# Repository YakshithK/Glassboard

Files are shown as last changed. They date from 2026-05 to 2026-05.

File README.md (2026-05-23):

# Glassboard

A transparent NFC business card that lights up when you tap your phone to it. No battery. No charging. Ever.

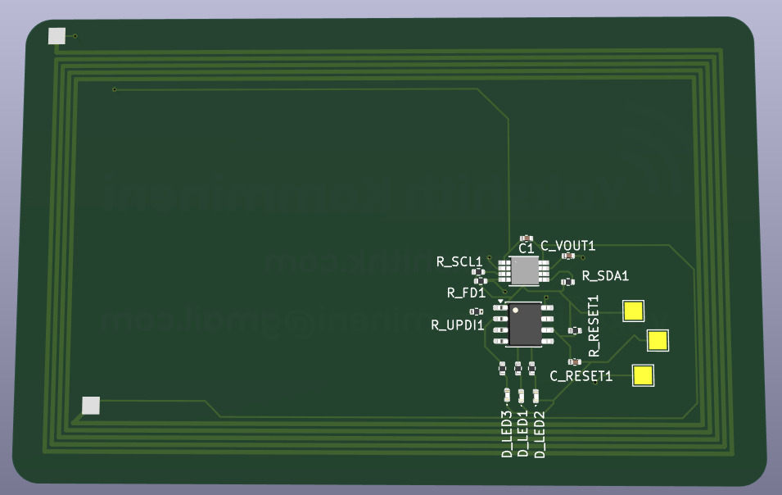
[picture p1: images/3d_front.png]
3D Front

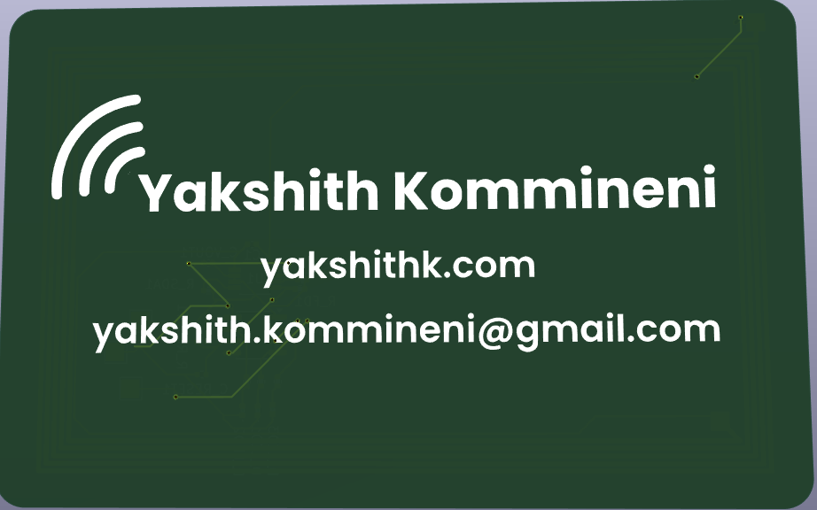
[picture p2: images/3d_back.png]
3D Back


---

## What is it

Glassboard is a credit card sized transparent circuit board. It stores my contact info and portfolio link using NFC. When someone taps their phone to it, two things happen at once: their phone opens my portfolio link, and three green LEDs on the card light up and animate.

The entire card runs off the energy from the phone's own NFC signal. There is no battery inside. Nothing to charge. The card just sits in your wallet and works whenever someone taps it.

Because it's built on a transparent substrate, you can see through the card. Every trace, every component, and the antenna spiral are all visible. It looks like a piece of glass with circuits inside.

---

## Why I made it

I kept handing people plain paper business cards at hackathons. It felt wrong. I build hardware, but the card said nothing about that.

I wanted a card that proved what I do the moment someone touched it. So I built one.

---

## How it works

The card has two chips on it.

The first is the **NT3H2111**, an NFC chip from NXP. It stores my URL in its memory and harvests power from the phone's NFC field. When a phone gets close, the chip outputs around 3V on its power pin, which powers everything else on the card.

The second is the **ATtiny202**, a tiny microcontroller. It spends almost all of its time asleep, drawing basically no power. When the NFC chip detects a phone, it sends a signal to the ATtiny, which wakes up instantly, runs the LED animation for about 2 seconds, then goes back to sleep.

The antenna is a copper spiral coil built directly into the circuit board. It has 5 turns and is tuned to 13.56 MHz, which is the frequency all NFC phones use.

The three LEDs are green because green LEDs turn on at a lower voltage than blue or white ones, which matters a lot when you're running off harvested power.

---

## How to use it

**Tapping it:**
Hold the card against the back of any NFC enabled phone (most smartphones made after 2015 have NFC). The phone will show a notification to open a link. Tap it. The LEDs on the card will also light up at the same time.

If nothing happens, try moving the card around slowly. The NFC antenna in phones is usually near the top or center of the back.

**Changing the URL:**
1. Download the NXP TagWriter app (free on both iOS and Android)
2. Open the app and select "Write"
3. Choose "Link" and type in the URL you want
4. Hold your phone to the card
5. Done. The old URL is replaced with the new one

No programmer needed for this. The NFC chip handles it wirelessly.

**Reprogramming the LED animation:**
1. Get a CH340 USB to UART adapter (about $3 on Amazon)
2. Connect it to the three small pads on the bottom edge of the card: VCC, GND, and UPDI
3. Install megaTinyCore in Arduino IDE (add this URL to board manager: `http://drazzy.com/package_drazzy.com_index.json`)
4. Select board: ATtiny202, clock: 5MHz internal, programmer: UPDI
5. Open `firmware/glassboard.ino` and upload

---

## PCB

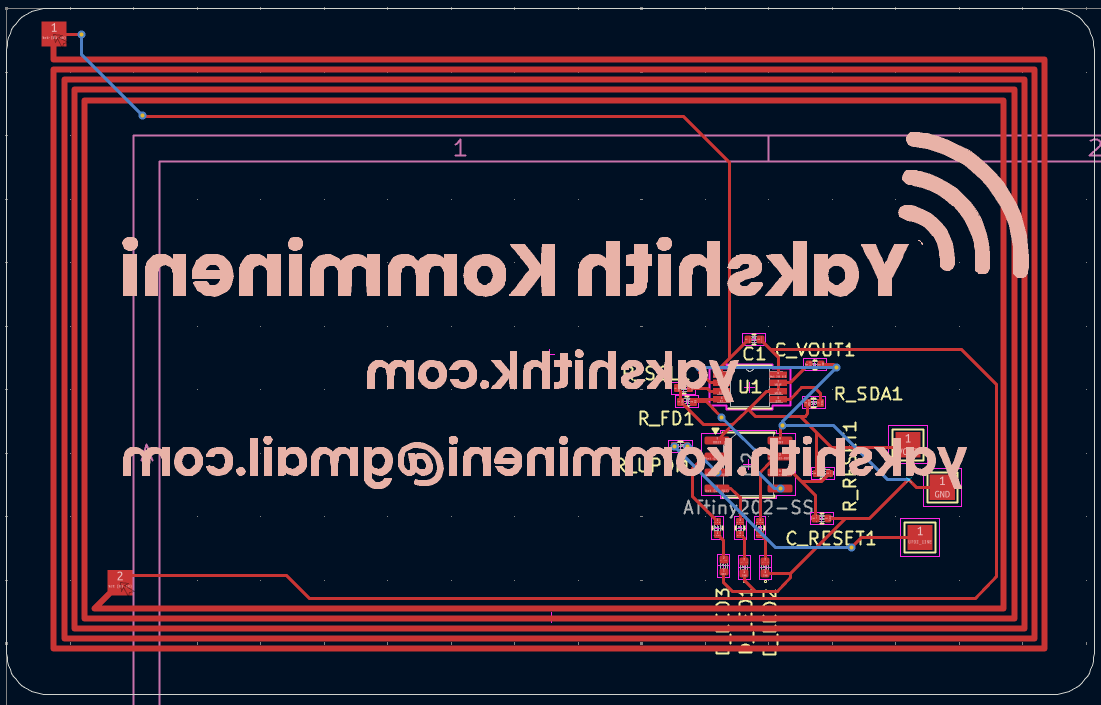
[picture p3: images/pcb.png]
PCB Layout

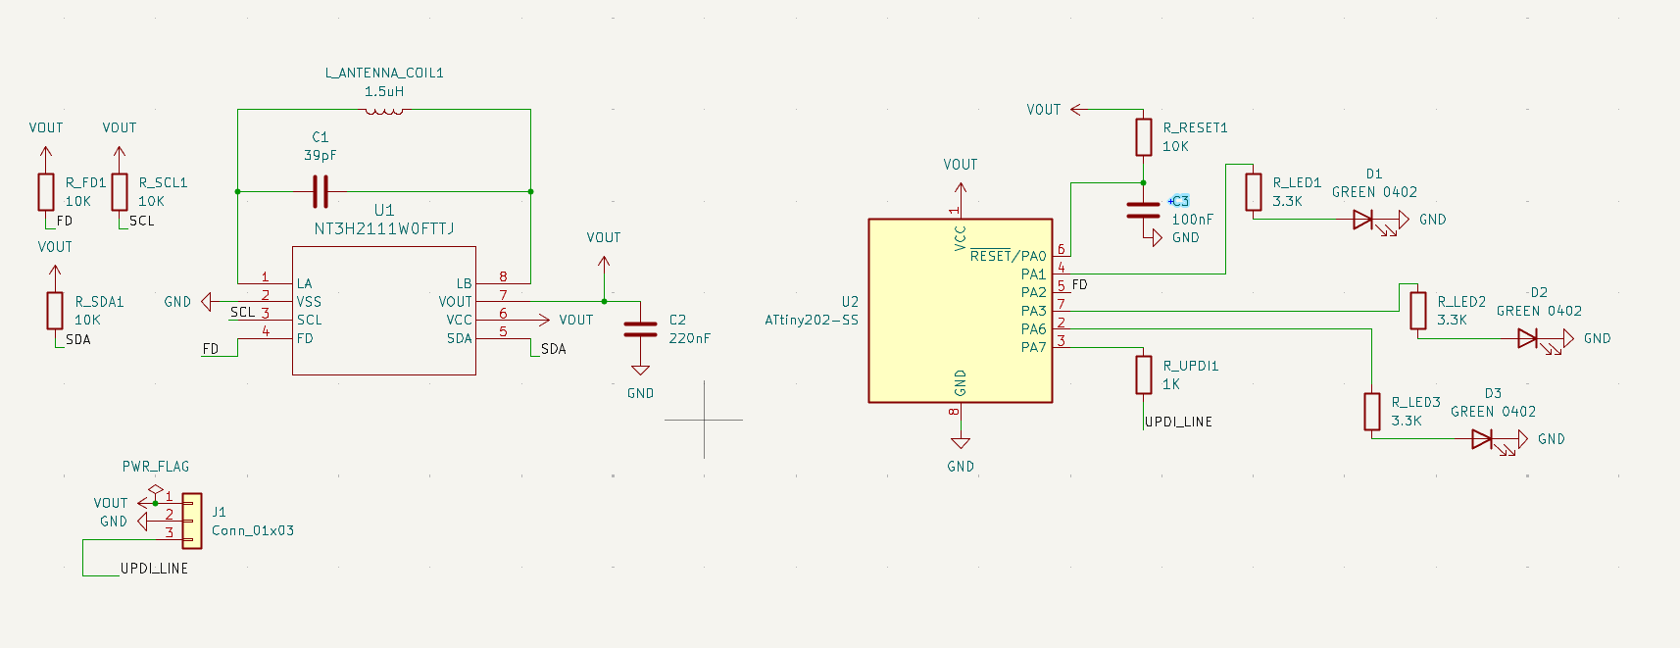
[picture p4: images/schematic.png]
Schematic


| Spec | Value |
|---|---|
| Substrate | Transparent FPC (PET) |
| Layers | 2 |
| Thickness | 0.2mm |
| Dimensions | 85.6 x 54mm (credit card size) |
| Surface finish | ENIG (gold) |
| Made by | JLCPCB |

---

## Parts list

Full BOM with purchase links is in `BOM.csv`.

| Part | Description | Quantity |
|---|---|---|
| NT3H2111W0FTT | NFC chip, TSSOP8 | 1 |
| ATtiny202-SSF | Microcontroller, SOIC8 | 1 |
| Wurth 150040GS73240 | Green LED, 0402 | 3 |
| 220nF cap | Decoupling, 0402 | 1 |
| 100nF cap | RESET filter, 0402 | 1 |
| 39pF cap | Antenna tuning, 0402 | 1 |
| 10pF cap | Optional tuning, 0402 (DNP) | 1 |
| 10k resistor | Pull-ups, 0402 | 4 |
| 3.3k resistor | LED current limit, 0402 | 3 |
| 1k resistor | UPDI protection, 0402 | 1 |
| Transparent FPC PCB | From JLCPCB | 1 |

Total cost is around $32 for 5 boards including shipping.

---

## Firmware

The firmware file is at `firmware/glassboard.ino`.

It puts the ATtiny202 into deep sleep mode. When the NT3H2111 detects a phone, its FD pin goes LOW, which triggers a hardware interrupt on the ATtiny. The MCU wakes up, runs a chase animation across the three LEDs, then goes back to sleep. The whole active cycle takes about 2 seconds.

---

## Files

```
glassboard/
├── README.md
├── BOM.csv
├── firmware/
│   └── glassboard.ino
├── hardware/
│   ├── glassboard.kicad_pro
│   ├── glassboard.kicad_sch
│   ├── glassboard.kicad_pcb
│   └── gerbers/
├── Glassboard_Zine.pdf
└── images/
    ├── 3d_front.png
    ├── 3d_back.png
    ├── pcb.png
    ├── schematic.png
    └── zine.png
```

---

## Zine page

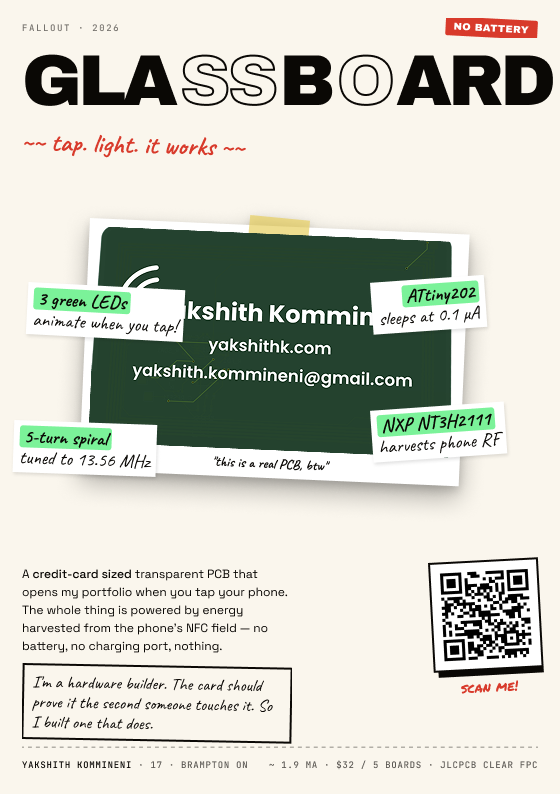
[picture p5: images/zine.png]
Zine


---

Made by Yakshith Kommineni, age 17, Brampton Ontario Canada

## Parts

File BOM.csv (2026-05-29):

Reference | Description | Value | Package | Quantity | Manufacturer | Part Number | Link | Unit Cost (USD) | Notes
U1 | NFC Energy Harvesting IC | NT3H2111W0FTT | TSSOP-8 | 1 | NXP | NT3H2111W0FTT | https://www.digikey.ca/en/products/detail/nxp-usa-inc/NT3H2111W0FTTJ/5872979 | 1.20
U2 | Microcontroller | ATtiny202-SSF | SOIC-8 | 1 | Microchip | ATtiny202-SSF | https://www.digikey.ca/en/products/detail/microchip-technology/ATTINY202-SSF/9947533 | 0.50
D1-D3 | Green LED 0402 | 150040GS73240 | 0402 | 3 | Würth Elektronik | 150040GS73240 | https://www.digikey.ca/en/products/detail/w%C3%BCrth-elektronik/150040GS73240/8557155 | 0.3
C2 | Decoupling Cap VOUT | 220nF | 0402 | 1 | Samsung | CL05A224KP5NNNC | https://www.digikey.ca/en/products/detail/samsung-electro-mechanics/CL05A224KP5NNNC/3886707 | 0.10
C3 | RESET Decoupling Cap | 100nF | 0402 | 1 | Samsung | CL05B104KO5NNNC | https://www.digikey.ca/en/products/detail/samsung-electro-mechanics/CL05B104KO5NNNC/3886659 | 0.10
C1 | Antenna Tuning Cap | 39pF | 0402 | 1 | Murata | GJM1555C1H390FB01D | https://www.digikey.com/en/products/detail/murata-electronics/GJM1555C1H390FB01D/7362928411388 | 0.14
R1-R4 | FD/SCL/SDA/RESET Pull-up | 10kΩ | 0402 | 4 | Stackpole Electronics Inc | RMCF0402FT10K0 | https://www.digikey.ca/en/products/detail/stackpole-electronics-inc/RMCF0402FT10K0/1761433 | 0.10
R5 | UPDI Series Resistor | 1kΩ | 0402 | 1 | Stackpole Electronics Inc | RMCF0402FT1K00 | https://www.digikey.ca/en/products/detail/stackpole-electronics-inc/RMCF0402FT1K00/1761754 | 0.10
R6-R8 | LED1-LED3 Current Limit | 3.3kΩ | 0402 | 3 | Stackpole Electronics Inc | RMCF0402FT3K30 | https://www.digikey.com/en/products/detail/stackpole-electronics-inc/RMCF0402FT3K30/2417445 | 0.10
PCB | Transparent FPC PCB | Glassboard | 85.6x54mm | 5 | JLCPCB |  | https://jlcpcb.com | 6.40 | ENIG finish / 0.2mm / 2 layer / transparent FPC - price per board for qty 5
TOTAL |  |  |  |  |  |  |  | $34.87

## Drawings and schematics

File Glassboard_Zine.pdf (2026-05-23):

# GLASSBOARD

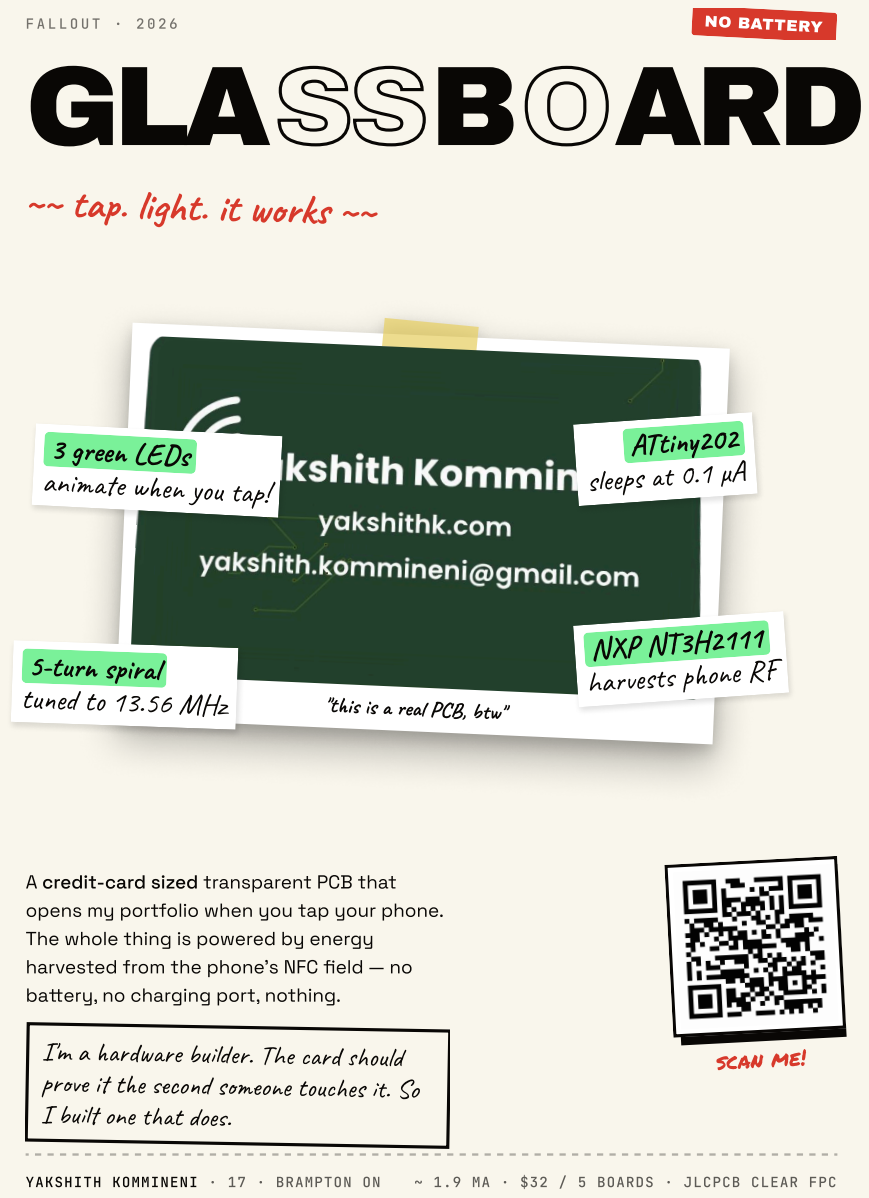
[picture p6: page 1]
NO BATTERY; ATtiny202; 5-turn spiral; NXP NT3H2111; Yakshith Kommineni · 17 · Brampton ON; $32 / 5 boards ·; JLCPCB clear FPC; scan me!

~~ tap. light. it works ~~

3 green LEDs sleeps at 0.1 µA

animate when you tap!

harvests phone RF

tuned to 13.56 MHz

"this is a real PCB, btw"

A credit-card sized transparent PCB that

opens my portfolio when you tap your phone.

The whole thing is powered by energy

harvested from the phone's NFC field — no

battery, no charging port, nothing.

I'm a hardware builder. The card should

prove it the second someone touches it. So

I built one that does.

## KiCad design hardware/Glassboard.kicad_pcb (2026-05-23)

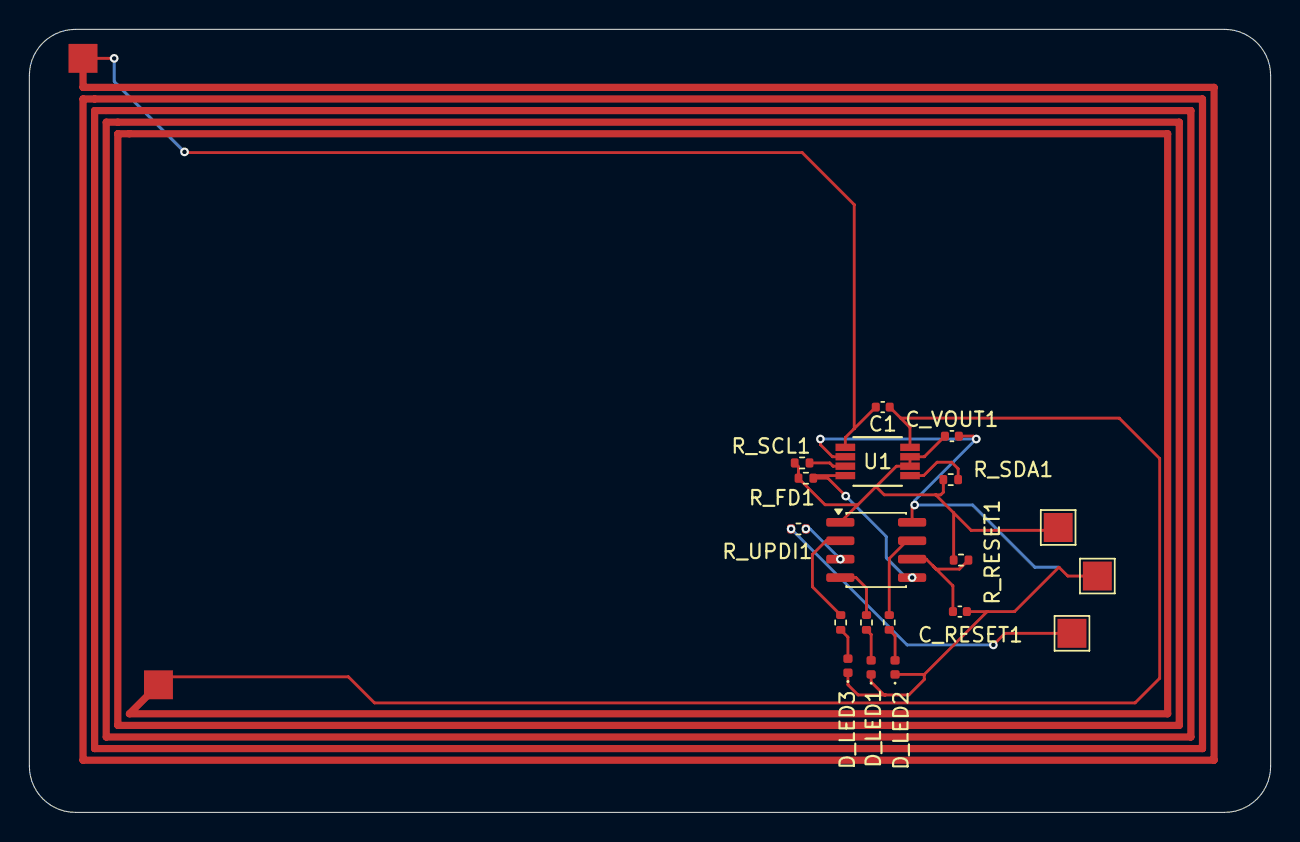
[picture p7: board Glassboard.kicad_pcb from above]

Board: 2 copper layers, 85.6 x 54.0 mm, 17 parts (0 on the bottom side), 15 nets.

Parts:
C1: 39pF; C_0402_1005Metric
C_RESET1: 100nF; C_0402_1005Metric
C_VOUT1: 220nF; C_0402_1005Metric
D_LED1, D_LED2, D_LED3: GREEN 0402; LED_0402_1005Metric
L_ANTENNA_COIL1: 1.5uH; NFC_Credit_Card
R_FD1: 10K; R_0402_1005Metric
R_LED1, R_LED2, R_LED3: 3.3K; R_0402_1005Metric
R_RESET1: 10K; R_0402_1005Metric
R_SCL1: 10K; R_0402_1005Metric
R_SDA1: 10K; R_0402_1005Metric
R_UPDI1: 1K; R_0402_1005Metric
U1: TSSOP_1W0FTTJ_NXP; NT3H2111W0FTTJ
U2: ATtiny202-SS; SOIC-8_3.9x4.9mm_P1.27mm

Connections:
/FD: R_FD1.2, U1.4 (FD), U2.5 (PA2)
/SCL: R_SCL1.2, U1.3 (SCL)
/SDA: R_SDA1.2, U1.5 (SDA)
GND: C_RESET1.2, C_VOUT1.2, D_LED1.1 (K), D_LED2.1 (K), D_LED3.1 (K), U1.2 (VSS), U2.8 (GND)
unnamed: D_LED1.2 (A), R_LED1.2
unnamed: D_LED2.2 (A), R_LED2.2
unnamed: D_LED3.2 (A), R_LED3.2
unnamed: C1.2, L_ANTENNA_COIL1.1, U1.1 (LA)
unnamed: C1.1, L_ANTENNA_COIL1.2, U1.8 (LB)
unnamed: R_LED1.1, U2.4 (PA1)
unnamed: R_LED2.1, U2.7 (PA3)
unnamed: R_LED3.1, U2.2 (PA6)
unnamed: R_UPDI1.1, U2.3 (PA7)
unnamed: C_RESET1.1, R_RESET1.2, U2.6 (~RESET/PA0)
VOUT: C_VOUT1.1, R_FD1.1, R_RESET1.1, R_SCL1.1, R_SDA1.1, U1.6 (VCC), U1.7 (VOUT), U2.1 (VCC)

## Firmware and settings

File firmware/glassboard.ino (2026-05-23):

/*
 * Glassboard — NFC Business Card Firmware
 * ATtiny202 / megaTinyCore
 * 
 * Behavior:
 *   - Deep sleep at ~0.1uA drawing essentially nothing
 *   - NT3H2111 FD pin goes LOW when phone NFC field detected
 *   - PA2 interrupt wakes MCU instantly
 *   - Runs LED animation sequence (~2 seconds)
 *   - Goes back to sleep
 * 
 * Pin assignments:
 *   PA2 - FD input from NT3H2111 (interrupt, active LOW)
 *   PA1 - LED1
 *   PA3 - LED2
 *   PA6 - LED3
 *   PA7 - UPDI (programming, do not use)
 *   PA0 - RESET (do not use)
 */

#include <avr/sleep.h>
#include <avr/interrupt.h>

#define LED1 PIN_PA1
#define LED2 PIN_PA3
#define LED3 PIN_PA6
#define FD_PIN PIN_PA2

// animation timing ms
#define STEP_DELAY 80
#define PULSE_DELAY 40

void allOff() {
  digitalWrite(LED1, LOW);
  digitalWrite(LED2, LOW);
  digitalWrite(LED3, LOW);
}

void allOn() {
  digitalWrite(LED1, HIGH);
  digitalWrite(LED2, HIGH);
  digitalWrite(LED3, HIGH);
}

// chase: 1 -> 2 -> 3 -> all -> off, repeat
void runAnimation() {
  // chase forward
  for (int i = 0; i < 3; i++) {
    digitalWrite(LED1, HIGH); delay(STEP_DELAY);
    digitalWrite(LED1, LOW);
    digitalWrite(LED2, HIGH); delay(STEP_DELAY);
    digitalWrite(LED2, LOW);
    digitalWrite(LED3, HIGH); delay(STEP_DELAY);
    digitalWrite(LED3, LOW);
  }

  // all flash 3x
  for (int i = 0; i < 3; i++) {
    allOn();  delay(PULSE_DELAY * 2);
    allOff(); delay(PULSE_DELAY);
  }

  // slow fade out (PWM approximation via toggling)
  for (int brightness = 10; brightness > 0; brightness--) {
    allOn();  delay(brightness * 3);
    allOff(); delay((10 - brightness) * 3);
  }

  allOff();
}

// interrupt service routine — just wakes MCU, no action needed
ISR(PORTA_PORT_vect) {
  // clear the interrupt flag for PA2
  PORTA.INTFLAGS = PIN2_bm;
}

void goToSleep() {
  // configure PA2 as input with pullup, trigger on falling edge (FD goes LOW)
  pinMode(FD_PIN, INPUT_PULLUP);
  PORTA.PIN2CTRL = PORT_PULLUPEN_bm | PORT_ISC_FALLING_gc;

  set_sleep_mode(SLEEP_MODE_PWR_DOWN);
  sleep_enable();
  sei();
  sleep_cpu();       // MCU stops here until interrupt
  sleep_disable();
  cli();
}

void setup() {
  pinMode(LED1, OUTPUT);
  pinMode(LED2, OUTPUT);
  pinMode(LED3, OUTPUT);
  allOff();

  // brief startup flash so you know it programmed correctly
  allOn(); delay(100); allOff();
}

void loop() {
  goToSleep();       // sleep until phone tap
  runAnimation();    // phone tapped — animate
  // loop: go back to sleep
}

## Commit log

2026-05-23 remove duplicate kicad files
2026-05-23 Update BOM with new components and pricing
    Updated component details including manufacturers and links, and adjusted quantities and costs.
    [BOM.csv]
2026-05-23 Update BOM.csv with new components and details
    [BOM.csv]
2026-05-23 Modify capacitor entries in BOM.csv
    Updated the BOM to replace C3 and C4 with C2 and C3, respectively.
    [BOM.csv]
2026-05-23 fixed schematic names
    [Glassboard.kicad_sch]
2026-05-29 Include total cost in BOM.csv
    Added total cost calculation for BOM.
    [BOM.csv]
